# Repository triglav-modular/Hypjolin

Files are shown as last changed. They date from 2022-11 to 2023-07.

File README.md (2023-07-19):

# Hypjolin

The Hypjolin is a cross-modulating ultra-chaos generator device which combines Rob Hordijk’s Benjolin and Ian Fritz’s Hypster circuits. 
By merging the Benjolin’s stepped chaos with the Hypster’s smooth, fluctuating chaos, the Hypjolin produces remarkably unpredictable, yet controllable sonic outcomes.  
The integration of these two systems is facilitated through a banana jack patchbay, with blue banana jacks representing Benjolin outputs and purple ones denoting Hypster outputs. The black jacks serve as inputs. The patch bay is spaced for use with shorting bars.

hypjolin_hero
hypjolin_hero_back

Mouser Cart: https://www.mouser.com/ProjectManager/ProjectDetail.aspx?AccessID=39b2feea56

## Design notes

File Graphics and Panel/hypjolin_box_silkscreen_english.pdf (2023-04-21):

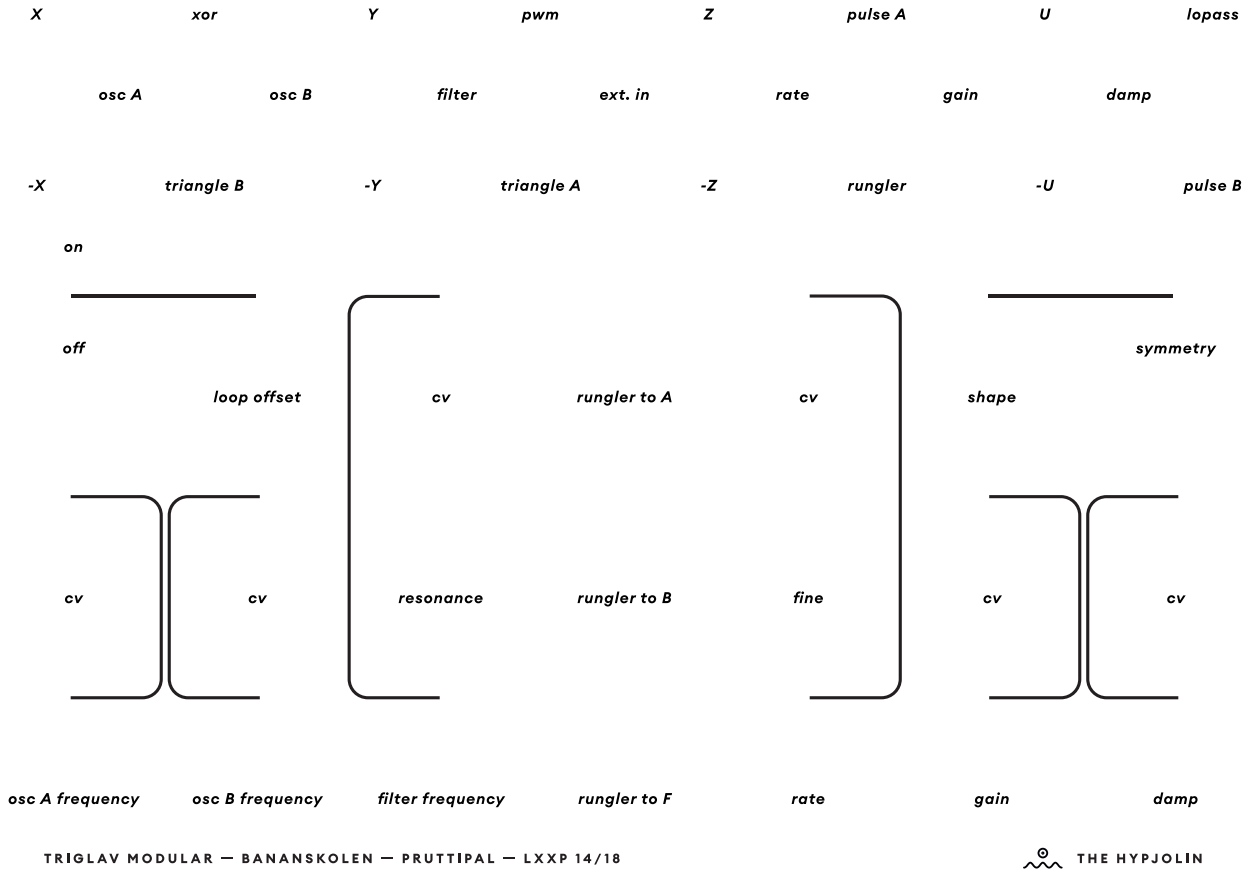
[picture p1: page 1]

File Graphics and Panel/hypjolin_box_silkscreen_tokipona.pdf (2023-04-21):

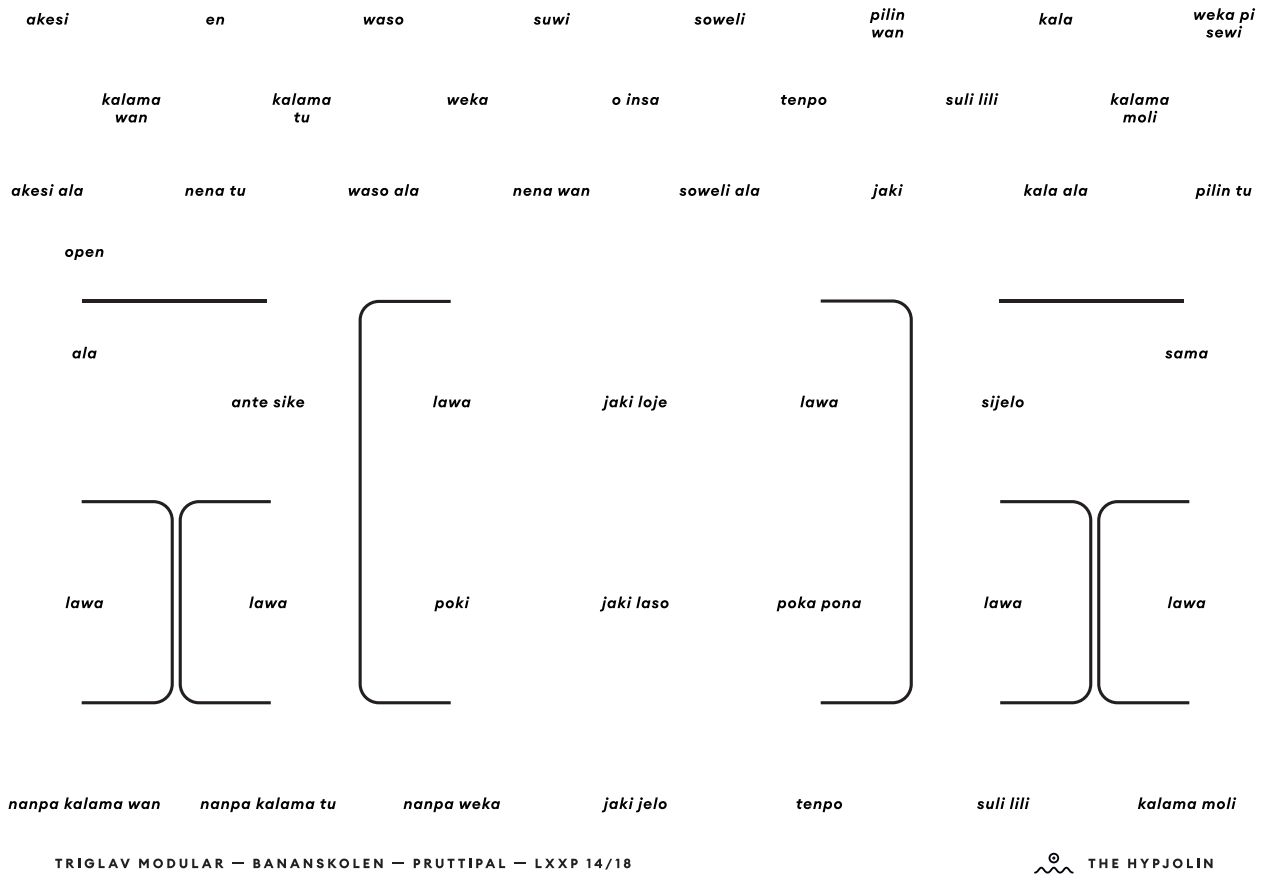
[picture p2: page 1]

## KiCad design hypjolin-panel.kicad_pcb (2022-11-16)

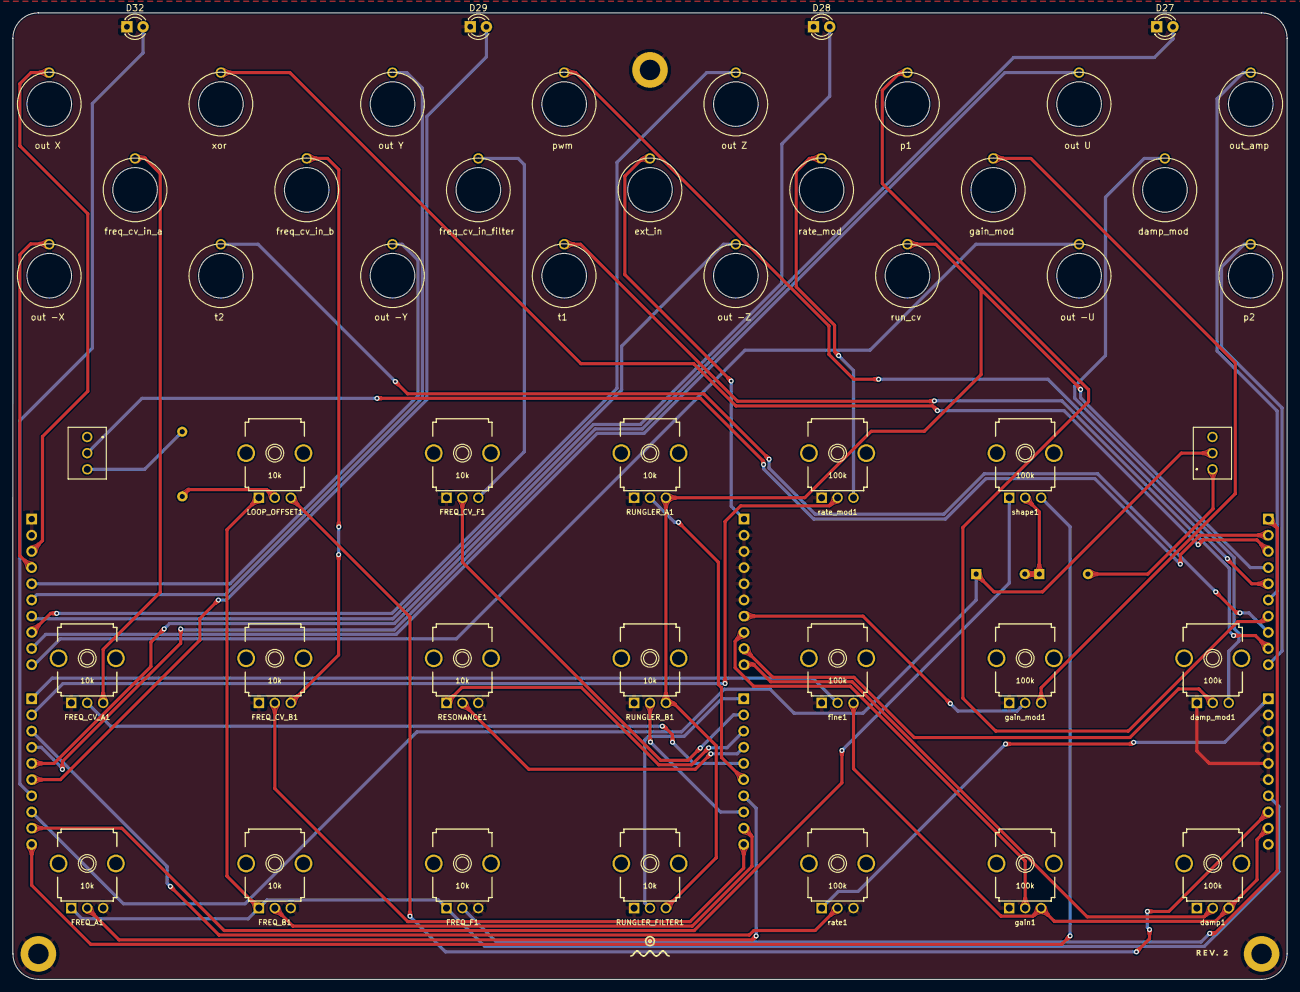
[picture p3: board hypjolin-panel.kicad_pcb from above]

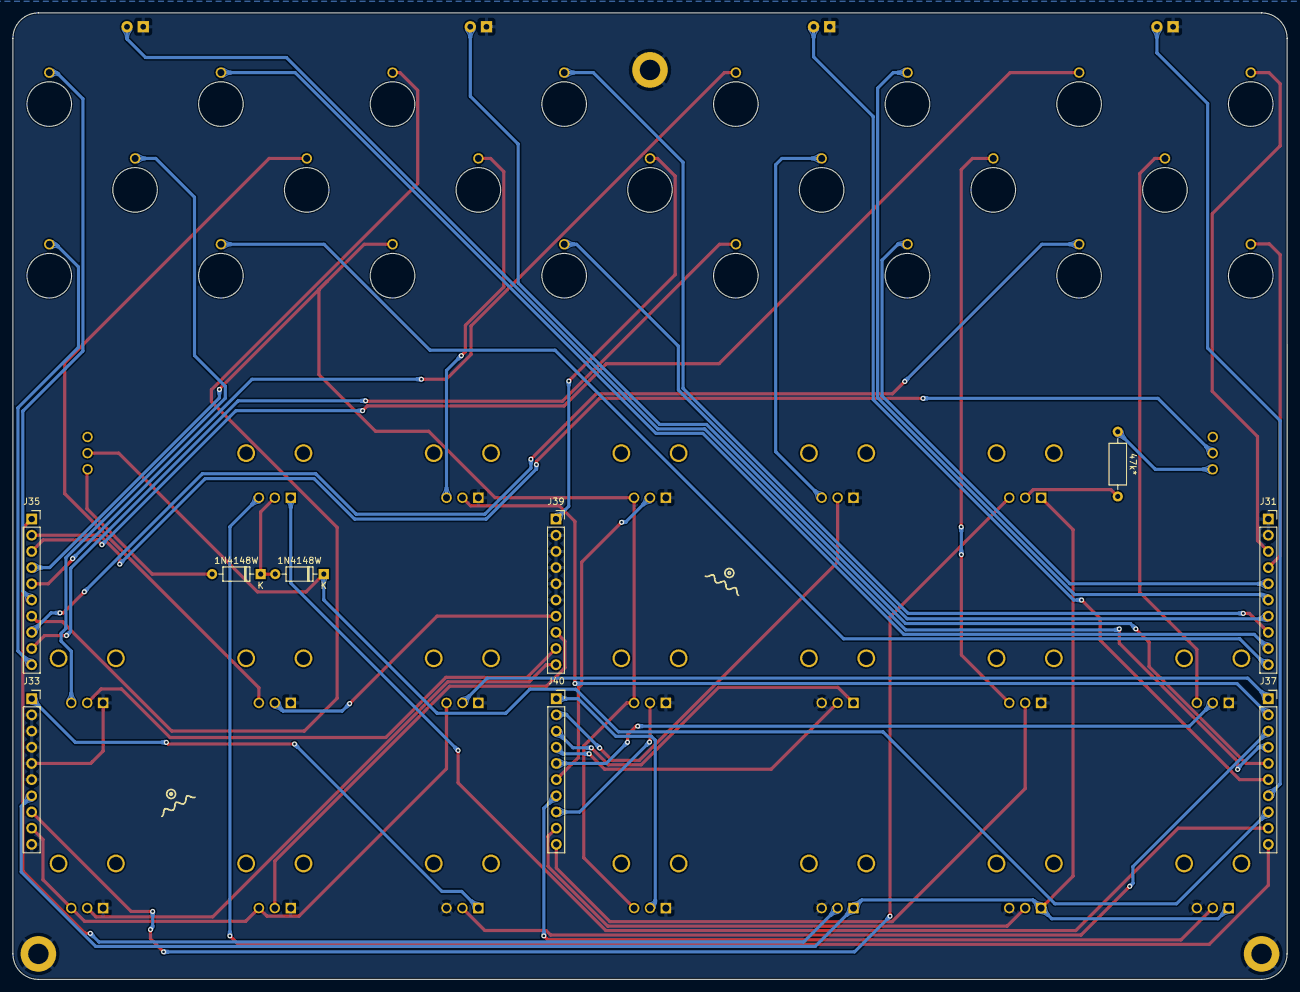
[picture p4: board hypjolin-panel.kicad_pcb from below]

Board: 2 copper layers, 200.0 x 151.7 mm, 57 parts (9 on the bottom side), 58 nets.

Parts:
D27: LED_Dual_Bidirectional_U; LED_D3.0mm_Clear
D28: LED_Dual_Bidirectional_Z; LED_D3.0mm_Clear
D29: LED_Dual_Bidirectional_Y; LED_D3.0mm_Clear
D30, D31: 1N4148W; D_DO-35_SOD27_P7.62mm_Horizontal
D32: LED_Dual_Bidirectional_X; LED_D3.0mm_Clear
FREQ_A1: 10k; MusicThingModular-9MM_SNAP-IN_POT
FREQ_B1: 10k; MusicThingModular-9MM_SNAP-IN_POT
FREQ_CV_A1: 10k; MusicThingModular-9MM_SNAP-IN_POT
FREQ_CV_B1: 10k; MusicThingModular-9MM_SNAP-IN_POT
FREQ_CV_F1: 10k; MusicThingModular-9MM_SNAP-IN_POT
FREQ_F1: 10k; MusicThingModular-9MM_SNAP-IN_POT
J1: freq_cv_in_a; Banana_Jack_1Pin
J2: freq_cv_in_b; Banana_Jack_1Pin
J3: ext_in; Banana_Jack_1Pin
J4: p2; Banana_Jack_1Pin
J5: t1; Banana_Jack_1Pin
J6: t2; Banana_Jack_1Pin
J7: p1; Banana_Jack_1Pin
J8: out_amp; Banana_Jack_1Pin
J9: pwm; Banana_Jack_1Pin
J10: run_cv; Banana_Jack_1Pin
J11: xor; Banana_Jack_1Pin
J12: freq_cv_in_filter; Banana_Jack_1Pin
J15: out -U; Banana_Jack_1Pin
J16: out U; Banana_Jack_1Pin
J17: out Z; Banana_Jack_1Pin
J18: out -Z; Banana_Jack_1Pin
J19: out Y; Banana_Jack_1Pin
J20: out -Y; Banana_Jack_1Pin
J21: out -X; Banana_Jack_1Pin
J22: out X; Banana_Jack_1Pin
J23: gain_mod; Banana_Jack_1Pin
J24: rate_mod; Banana_Jack_1Pin
J25: damp_mod; Banana_Jack_1Pin
J31: CONN_4_P; PinSocket_1x10_P2.54mm_Vertical
J33: CONN_5_P; PinSocket_1x10_P2.54mm_Vertical
J35: CONN_2_P; PinSocket_1x10_P2.54mm_Vertical
J37: CONN_6_P; PinSocket_1x10_P2.54mm_Vertical
J39: CONN_1_P; PinSocket_1x10_P2.54mm_Vertical
J40: CONN_3_P; PinSocket_1x10_P2.54mm_Vertical
LOOP_OFFSET1: 10k; MusicThingModular-9MM_SNAP-IN_POT
R18: 47k*; R_Axial_DIN0207_L6.3mm_D2.5mm_P10.16mm_Horizontal
RESONANCE1: 10k; MusicThingModular-9MM_SNAP-IN_POT
RUNGLER_A1: 10k; MusicThingModular-9MM_SNAP-IN_POT
RUNGLER_B1: 10k; MusicThingModular-9MM_SNAP-IN_POT
RUNGLER_FILTER1: 10k; MusicThingModular-9MM_SNAP-IN_POT
SW1, SW2: SUBMINI_SPDT; 1082MS1T1B1M2QEEVX
damp1: 100k; MusicThingModular-9MM_SNAP-IN_POT
damp_mod1: 100k; MusicThingModular-9MM_SNAP-IN_POT
fine1: 100k; MusicThingModular-9MM_SNAP-IN_POT
gain1: 100k; MusicThingModular-9MM_SNAP-IN_POT
gain_mod1: 100k; MusicThingModular-9MM_SNAP-IN_POT
rate1: 100k; MusicThingModular-9MM_SNAP-IN_POT
rate_mod1: 100k; MusicThingModular-9MM_SNAP-IN_POT
shape1: 100k; MusicThingModular-9MM_SNAP-IN_POT

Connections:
/P / LEDU: D27.2 (AK), J37.4
/P / LEDX: D32.2 (AK), J37.7
/P / LEDY: D29.2 (AK), J37.6
/P / LEDZ: D28.2 (AK), J37.5
/P / OUT_AMP: J8.1, J35.6
/P / P1: J7.1, J35.7
/P / P2: J4.1, J35.10
/P / PWM: J9.1, J35.5
/P / RUN_CV: J10.1, J35.4, RUNGLER_A1.3 (E), RUNGLER_B1.3 (E), RUNGLER_FILTER1.3 (E)
/P / T1: J5.1, J35.9
/P / T2: J6.1, J35.8
/P / XOR: J11.1, J35.3
/P / cv_f_pot: FREQ_CV_F1.2 (S), J40.2
/P / damp_mod: J25.1, damp_mod1.3 (E)
/P / damp_mod_pot: J39.9, damp_mod1.2 (S)
/P / damp_pot: J39.10, damp1.2 (S)
/P / ext_in: J3.1, J39.1
/P / fine_pot: J37.1, fine1.2 (S)
/P / freq_a_pot: FREQ_A1.2 (S), J40.7
/P / freq_b_pot: FREQ_B1.2 (S), J40.9
/P / freq_cv_a_pot: FREQ_CV_A1.2 (S), J40.5
/P / freq_cv_b_pot: FREQ_CV_B1.2 (S), J40.10
/P / freq_f_pot: FREQ_F1.2 (S), J35.1
/P / gain_mod: J23.1, gain_mod1.3 (E)
/P / gain_mod_pot: J39.7, gain_mod1.2 (S)
/P / gain_pot: J39.8, gain1.2 (S)
/P / offset_switch: J35.2, SW1.2 (COMMON)
/P / out -U: J15.1, J31.10
/P / out -X: J21.1, J31.4
/P / out -Y: J20.1, J31.5
/P / out -Z: J18.1, J31.7
/P / out U: J16.1, J31.9
/P / out X: J22.1, J31.3
/P / out Y: J19.1, J31.6
/P / out Z: J17.1, J31.8
/P / rate_mod: J24.1, rate_mod1.3 (E)
/P / rate_mod_pot: J37.2, rate_mod1.2 (S)
/P / rate_pot: J37.3, rate1.2 (S)
/P / reso_pot_A: J40.4, RESONANCE1.2 (S)
/P / reso_pot_B: J40.3, RESONANCE1.1 (A)
/P / run_a_pot: J40.6, RUNGLER_A1.2 (S)
/P / run_b_pot: J40.8, RUNGLER_B1.2 (S)
/P / run_f_pot: J40.1, RUNGLER_FILTER1.2 (S)
/P / shape_IN1: J37.10, shape1.3 (E)
/P / shape_IN2: J37.9, shape1.1 (A)
/P / shape_OUT: D30.1 (K), J37.8, SW2.2 (COMMON)
unnamed: D30.2 (A), D31.1 (K), shape1.2 (S)
unnamed: D31.2 (A), SW2.1 (O)
unnamed: FREQ_CV_A1.3 (E), J1.1
unnamed: FREQ_CV_B1.3 (E), J2.1
unnamed: FREQ_CV_F1.3 (E), J12.1
unnamed: LOOP_OFFSET1.2 (S), R18.1
unnamed: R18.2, SW1.3 (S)
P / GND: D27.1 (KA), D28.1 (KA), D29.1 (KA), D32.1 (KA), FREQ_A1.3 (E), FREQ_B1.3 (E), FREQ_CV_A1.1 (A), FREQ_CV_B1.1 (A), FREQ_CV_F1.1 (A), FREQ_F1.3 (E), J31.1, J31.2, J33.2, J33.3, J33.4, J33.5, J33.6, J33.10, J39.2, J39.3, J39.4, J39.5, J39.6, RESONANCE1.3 (E), RUNGLER_A1.1 (A), RUNGLER_B1.1 (A), RUNGLER_FILTER1.1 (A), damp1.1 (A), damp_mod1.1 (A), fine1.1 (A), gain1.1 (A), gain_mod1.1 (A), rate1.3 (E), rate_mod1.1 (A)
P / V+: J33.8, LOOP_OFFSET1.3 (E)
P / V-: FREQ_A1.1 (A), FREQ_B1.1 (A), FREQ_F1.1 (A), J33.7, LOOP_OFFSET1.1 (A)
P / VCC: J33.9, damp1.3 (E), fine1.3 (E), gain1.3 (E)
P / VEE: J33.1, rate1.1 (A)

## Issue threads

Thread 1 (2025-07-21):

Hipster side not working but...

stilltryin, 2025-07-21:
Hey, i managed somehow to get the benjolin set to work but the hipster side doesn't, got voltage on the pots and all but nothing happens when i turn them plus the LED stay on all the time except i flick the symmetry switch the second left turn pos to negative...do you by chance have any suggestion to where to start trouble shot? Thanks in any case...

Closed 2025-08-17.

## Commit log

2022-08-25 board cleanup
2022-08-26 cleanup / fixes
    [hypjolin.kicad_sch, hypjolin_panel_cutout2.dxf, hypjolin_panel_cutout_v2.dxf]
2022-08-29 add mounting holes, wider power tracks
2022-08-29 silkscreen fixes
    [hypjolin.kicad_sch]
2022-08-31 silkscreen, trace cleanup
2022-08-31 track cleanup
2022-08-31 cleanup folders
    [hypjolin_panel_cutout.dxf, hypjolin_panel_photo_v2.dxf]
2022-08-31 track cleanup, 3D model update
    [hypjolin.kicad_sch]
2022-09-05 board fixes
    [hypjolin.kicad_sch]
2022-09-19 first prototype
    [hypjolin.kicad_sch]
2022-11-16 Rev.2
    Fix issues with rev.1, add TT version
    [hypjolin-panel.kicad_pcb, hypjolin-tt-jacks.kicad_pcb, hypjolin-tt-pots.kicad_pcb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]
2023-07-19 Cleaned up panel graphics file
    [hypjolin.kicad_sch]
